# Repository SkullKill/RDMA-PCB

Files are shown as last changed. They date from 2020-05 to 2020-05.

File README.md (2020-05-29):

# RDMA-PCB
Rpi Dead Man Alarm - PCB and 3D case - Occupancy Monitoring - Raspberry Pi hat

24-RDMA-Case-04.jpg


23-RDMA-Case-03.jpg


07-RDMAweb-02.jpg


Video of it in action
Video of it in action (https://youtu.be/Ym4e5IUdtps)

## V 1.0 29/05/2020 - Initial Release

  ------------------------------------------------------------
## PCB Board Used

Ready to use PCB Board

https://www.skstore.com.au/electronics/pcb/RDMA

PCB Design Files / gerber files

[RDMA-PCB](https://github.com/SkullKill/RDMA-PCB)

3D Printed Case design files / STL

[RDMA-PCB](https://github.com/SkullKill/RDMA-PCB)

https://www.thingiverse.com/thing:4406335

https://www.myminifactory.com/object/3d-print-123446

FYI Gerber files are in the release section

https://github.com/SkullKill/RDMA-PCB/releases

more pictures in the wiki

https://github.com/SkullKill/RDMA-PCB/wiki

18-RDMA-Wiring-01.jpg


10-RDMA-FrontR-V1.0.jpg


15-RDMA-Back-BoardOnly-V1.0.jpg


  ------------------------------------------------------------
## Schematics

09-RDMA-schematics-v1.0.jpg


  ------------------------------------------------------------
## MecanicalDrawing

1 to 1 scale 

https://github.com/SkullKill/RDMA-PCB/blob/master/Case/RDMAcase-MecanicalDrawing-V1.0.pdf

please use PDF version, and print to scale


  ------------------------------------------------------------
## Code Used

[RDMA](https://github.com/SkullKill/RDMA)

  ------------------------------------------------------------

PCB features

* Step down DC DC regulator (12v will power both the pi and PIR sensor)
* Input has a self reset fuse, and reverse polarity protection.
* Physical on/off switch when powered via 12v
* Back power protection to allow pi to provide power.
* RTC clock
* Segment display (to display time left before alarm is triggered)
* Ability to trigger 3 X 5V object (e.g buzzer or lights) (will probably only populate one for the buzzer)
* The above trigger can be set to either 5V or 12V.
* Built in buzzer (to alert operator 1 min before alarm is triggered and SMS are sent out)
* 1-wire rail (possibility to add a number of DS18B20 temperature sensors)
* 2 physical button, one to manually reset the timer, or if hold for a few sec, will extend the timer once. Other button is to shutdown/unused.
* Ability to add external buttons.
* 1 configurable status light. (on when the service is running)
* All button, including PIR input has a physical denounce to eliminate noise/false alarm.
* EEPROM as per pi hat requirement (will probably not populate)
* Screw terminal for all connectors. No crimping required.

---------------------------

A 12V , 1A PSU should work, however, to be on the safe side, use a 12V, 2A PSU

Standard wall mount sensor DG65
https://www.paradox.com/Products/default.asp?CATID=8&SUBCATID=79&PRD=1389

swivel mount for DG65
https://www.paradox.com/Products/default.asp?CATID=8&SUBCATID=81&PRD=456

---------------------------

if the service is not running after restarting, GPIO 8 would be on, which would make the buzzer turn on. to turn it off, use the following.

    gpio readall
    gpio -g mode 8 output
    gpio -g write 8 0

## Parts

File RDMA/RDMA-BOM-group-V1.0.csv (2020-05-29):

Reference | Quantity | Value | Footprint | Datasheet | Alt | LCSC | LCSCweb | MPN | ALT | MPNweb | web
BT1 | 1 | Coin_1220 | RDMA:BatteryHolder_Keystone_1056_1x1220 | https://datasheet.lcsc.com/szlcsc/Q-J-CR1220-2_C70381.pdf |  | C70381 | https://lcsc.com/product-detail/Battery-Holders-Clips-Contacts_CR1220-2-Battery-horizontal-base_C70381.html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 | CR1220-2 | C238067
BZ1 | 1 | Buzzer_Active | RDMA:Buzzer_9x5.5RM5.0 | https://datasheet.lcsc.com/szlcsc/1811141138_Jiangsu-Huaneng-Elec-HNB09A05_C96493.pdf |  | C96493 | https://lcsc.com/product-detail/Buzzers_Jiangsu-Huaneng-Elec-HNB09A05_C96493.html | HNB09A05
C4 C1 C7 | 3 | 22UF-25V | Capacitor_SMD:C_0805_2012Metric | https://datasheet.lcsc.com/szlcsc/Samsung-Electro-Mechanics-CL21A226MAQNNNE_C45783.pdf |  | C45783 | https://lcsc.com/product-detail/Multilayer-Ceramic-Capacitors-MLCC-SMD-SMT_SAMSUNG_CL21A226MAQNNNE_22uF-226-20-25V_C45783.html | CL21A226MAQNNNE | C86816
C5 C3 C6 C9 C2 C12 C10 C11 C8 | (9-2)=7 | 100nF-50V | Capacitor_SMD:C_0603_1608Metric | https://datasheet.lcsc.com/szlcsc/YAGEO-AC0603KRX7R9BB104_C149620.pdf |  | C149620 | https://lcsc.com/product-detail/Multilayer-Ceramic-Capacitors-MLCC-SMD-SMT_YAGEO-AC0603KRX7R9BB104_C149620.html | AC0603KRX7R9BB104
D1 D5 D7 | (3-1)=2 | SOD1F7 | Diode_SMD:D_SOD-123 | https://datasheet.lcsc.com/szlcsc/1903041730_MDD-Jiangsu-Yutai-Elec-SOD1F7_C33221.pdf |  | C33221 | https://lcsc.com/product-detail/Diodes-Rectifiers-Fast-Recovery_Jiangsu-Yutai-Elec-SOD1F7_C33221.html | SOD1F7
D11 D3 D6 | (3-1)=2 | LED-Yellow | LED_SMD:LED_0603_1608Metric | https://datasheet.lcsc.com/szlcsc/Foshan-NationStar-Optoelectronics-FC-DA1608HYK-588J_C84268.pdf |  | C84268 | https://lcsc.com/product-detail/Light-Emitting-Diodes-LED_Yellow-light-SMDLED-70-150mcd_C84268.html | FC-DA1608HYK-588J
D4 D2 | 2 | LED-Green | LED_SMD:LED_0603_1608Metric | https://datasheet.lcsc.com/szlcsc/Orient-ORH-G36G_C205443.pdf |  | C205443 | https://lcsc.com/product-detail/Light-Emitting-Diodes-LED_0603-green_C205443.html | ORH-G36G
F1 | 1 | PTC-2A-16V | Fuse:Fuse_1812_4532Metric_Pad1.30x3.40mm_HandSolder | https://datasheet.lcsc.com/szlcsc/SOCAY-Elec-SCF200-16-1812R_C305617.pdf |  | C305617 | https://lcsc.com/product-detail/Others_SOCAY-Elec-SCF200-16-1812R_C305617.html | SCF200-16-1812R
J1 | 1 | Raspberry_Pi_2_3 | Connector_PinSocket_2.54mm:PinSocket_2x20_P2.54mm_Vertical | https://www.raspberrypi.org/documentation/hardware/raspberrypi/schematics/rpi_SCH_3bplus_1p0_reduced.pdf | C35165 | C50982 | https://lcsc.com/product-detail/Pin-Header-Female-Header_Boom-Precision-Elec-2-54mm-2-20PFemale-header_C50982.html
J16 | 1 | 12Vpsu | pi-template:TerminalBlock_bornier-2_P5.08mm | https://datasheet.lcsc.com/szlcsc/Ningbo-Kangnex-Elec-WJ126V-5-0-2P_C8404.pdf |  | C8404 | https://lcsc.com/product-detail/Pluggable-System-Terminal-Block_Ningbo-Kangnex-Elec-WJ126V-5-0-2P_C8404.html | WJ126V-5.0-2P
J2 | 1 | Screw_Terminal_01x04_Left_Top | pi-template:TerminalBlock_TE_282834-4_1x04_P2.54mm_Horizontal | ~ |  |  |  | KF128-2.54-4P |  | http://en.cnkefa.com/index.php?c=product&id=159 | https://www.aliexpress.com/store/group/Connection-terminal/4657016_515213135.html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
J22 | 1 | ProgrammingJumper | Connector_PinHeader_2.54mm:PinHeader_1x02_P2.54mm_Vertical | ~ |  | C124375 | https://lcsc.com/product-detail/Pin-Header-Female-Header_Shenzhen-Cankemeng-Headers-Pins-1-2P-2-54mm-Straight-line_C124375.html
J3 | 1 | Screw_Terminal_01x04_Left_Bottom | pi-template:TerminalBlock_TE_282834-4_1x04_P2.54mm_Horizontal | ~ |  |  |  | KF128-2.54-4P |  | http://en.cnkefa.com/index.php?c=product&id=159 | https://www.aliexpress.com/store/group/Connection-terminal/4657016_515213135.html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
J4 | 1 | Screw_Terminal_01x08_Bottom_Left | pi-template:TerminalBlock_TE_282834-8_1x08_P2.54mm_Horizontal | ~ |  |  |  | KF128-2.54-8P |  | http://en.cnkefa.com/index.php?c=product&id=159
J5 | 1 | Screw_Terminal_01x06_Top_Right | pi-template:TerminalBlock_TE_282834-6_1x06_P2.54mm_Horizontal | ~ |  |  |  | KF128-2.54-6P |  | http://en.cnkefa.com/index.php?c=product&id=159
JP2 JP1 | 2 | SolderJumper_2_Open | Resistor_SMD:R_0805_2012Metric | https://datasheet.lcsc.com/szlcsc/YAGEO-RC0805JR-070RL_C96345.pdf |  | C96345 | https://lcsc.com/product-detail/Chip-Resistor-Surface-Mount_0R-0R-5_C96345.html | RC0805JR-070RL
JP3 JP7 | 2 | Jumper_3_Bridged12 | Connector_PinHeader_2.54mm:PinHeader_1x03_P2.54mm_Vertical | https://datasheet.lcsc.com/szlcsc/Boom-Precision-Elec-Header-2-54mm-1-3P_C49257.pdf |  | C49257 | https://lcsc.com/product-detail/Pin-Header-Female-Header_Boom-Precision-Elec-Header-2-54mm-1-3P_C49257.html
L1 | 1 | 3.3UH-8.5A | pi-template:L_6.3x6.3_H3_HandSolder | https://datasheet.lcsc.com/szlcsc/1812181433_MAZO-MPCA-0630-3R3-M_C268402.pdf |  | C268402 | https://lcsc.com/product-detail/Others_MAZO-MPCA-0630-3R3-M_C268402.html | MPCA-0630-3R3-M | C207839
Q11 | 1 | DMMT5401 | Package_TO_SOT_SMD:SOT-23-6 | https://datasheet.lcsc.com/szlcsc/Diodes-Incorporated-DMMT5401-7-F_C154733.pdf |  | C154733 | https://lcsc.com/product-detail/Transistors-NPN-PNP_DIODES_DMMT5401-7-F_DMMT5401-7-F_C154733.html | DMMT5401-7-F
Q12 Q1 | 2 | DMG2305UX | Package_TO_SOT_SMD:SOT-23 | https://datasheet.lcsc.com/szlcsc/Diodes-Incorporated-DMG2305UX-13_C144153.pdf |  | C144153 | https://lcsc.com/product-detail/MOSFET_Diodes-Incorporated_DMG2305UX-13_Diodes-Incorporated-DMG2305UX-13_C144153.html | DMG2305UX-13
Q2 Q6 Q7 | 3 | BSS138 | Package_TO_SOT_SMD:SOT-23 | https://datasheet.lcsc.com/szlcsc/Diodes-Incorporated-BSS138-7-F_C40912.pdf |  | C40912 | https://lcsc.com/product-detail/MOSFET_Diodes-Incorporated_BSS138-7-F_Diodes-Incorporated-BSS138-7-F_C40912.html | BSS138-7-F
Q3 Q4 Q5 | 3 | DMN2056U | Package_TO_SOT_SMD:SOT-23 | http://www.diodes.com/assets/Datasheets/DMN2056U.pdf |  | C332302 | https://lcsc.com/product-detail/MOSFET_Diodes-Incorporated_DMN2056U-7_Diodes-Incorporated-DMN2056U-7_C332302.html | DMN2056U-7
R1 R13 R17 | (3-1)=2 | 2.2KΩ | Resistor_SMD:R_0603_1608Metric | https://datasheet.lcsc.com/szlcsc/YAGEO-RC0603FR-072K2L_C114662.pdf |  | C114662 | https://lcsc.com/product-detail/Chip-Resistor-Surface-Mount_2-2KR-2201-1_C114662.html | RC0603FR-072K2L
R15 | 1 | 47KΩ | Resistor_SMD:R_0603_1608Metric | https://datasheet.lcsc.com/szlcsc/YAGEO-AC0603FR-0747KL_C111134.pdf |  | C111134 | https://lcsc.com/product-detail/Chip-Resistor-Surface-Mount_47KR-4702-1_C111134.html | AC0603FR-0747KL | RC0603FR-0747KL
R19 | (1-1)=0 | 1KΩ | Resistor_SMD:R_0603_1608Metric | https://datasheet.lcsc.com/szlcsc/YAGEO-RC0603FR-071KL_C22548.pdf |  | C22548 | https://lcsc.com/product-detail/Chip-Resistor-Surface-Mount_1KR-1001-1_C22548.html | RC0603FR-071KL
R21 R23 R24 | 3 | 4.7KΩ | Resistor_SMD:R_0603_1608Metric | https://datasheet.lcsc.com/szlcsc/YAGEO-RC0603FR-074K7L_C99782.pdf |  | C99782 | https://lcsc.com/product-detail/Chip-Resistor-Surface-Mount_4-7KR-472-1_C99782.html | RC0603FR-074K7L
R22 R28 | (2-2)=0 | 3.9KΩ | Resistor_SMD:R_0603_1608Metric | https://datasheet.lcsc.com/szlcsc/YAGEO-RC0603FR-073K9L_C114616.pdf |  | C114616 | https://lcsc.com/product-detail/Chip-Resistor-Surface-Mount_3-9KR-3901-1_C114616.html | RC0603FR-073K9L
R26 | 1 | 57.6KΩ | Resistor_SMD:R_0603_1608Metric | https://datasheet.lcsc.com/szlcsc/YAGEO-RC0603FR-0757K6L_C245983.pdf |  | C245983 | https://lcsc.com/product-detail/Others_YAGEO-RC0603FR-0757K6L_C245983.html | RC0603FR-0757K6L
R27 R6 R35 | (3-1)=2 | 330Ω | Resistor_SMD:R_0603_1608Metric | https://datasheet.lcsc.com/szlcsc/YAGEO-RC0603FR-07330RL_C105881.pdf |  | C105881 | https://lcsc.com/product-detail/Chip-Resistor-Surface-Mount_330R-330R-1_C105881.html | RC0603FR-07330RL
R34 R32 R7 | 3 | 1.2KΩ | Resistor_SMD:R_0603_1608Metric | https://datasheet.lcsc.com/szlcsc/YAGEO-RC0603FR-071K2L_C114605.pdf |  | C114605 | https://lcsc.com/product-detail/Chip-Resistor-Surface-Mount_1-2KR-1201-1_C114605.html | RC0603FR-071K2L
R4 R25 R11 R2 R8 R12 R16 R33 R31 R18 R29 R20 R30 | (13-2)=11 | 10KΩ | Resistor_SMD:R_0603_1608Metric | https://datasheet.lcsc.com/szlcsc/YAGEO-RC0603FR-0710KL_C98220.pdf |  | C98220 | https://lcsc.com/product-detail/Chip-Resistor-Surface-Mount_10KR-1002-1_C98220.html | RC0603FR-0710KL
R5 R3 R10 R14 | (4-1)=3 | 100Ω | Resistor_SMD:R_0603_1608Metric | https://datasheet.lcsc.com/szlcsc/YAGEO-RC0603FR-07100RL_C105588.pdf |  | C105588 | https://lcsc.com/product-detail/Chip-Resistor-Surface-Mount_100R-1000-1_C105588.html | RC0603FR-07100RL
SW1 | 1 | 5V Reg Sw on-off | Button_Switch_SMD:SW_SPDT_PCM12 | https://datasheet.lcsc.com/szlcsc/Korean-Hroparts-Elec-K3-1292S-P2_C145853.pdf |  | C145853 | https://lcsc.com/product-detail/Toggle-Switches_Korean-Hroparts-Elec-K3-1292S-P2_C145853.html | K3-1292S-P2
SW3 SW2 | 2 | SW_Push | RDMA:SW_SPST_TL3305A | ~ |  | C174049 | https://lcsc.com/product-detail/Tactile-Switches_Switch-4-5-4-5-3-8mm_C174049.html
U1 | 1 | TPS563200 | Package_TO_SOT_SMD:SOT-23-6_Handsoldering | http://www.ti.com/lit/ds/symlink/tps563200.pdf |  | C97253 | https://lcsc.com/product-detail/DC-DC-Converters_TI_TPS563200DDCR_TPS563200DDCR_C97253.html | TPS563200DDCR
U2 | (1-1)=0 | CAT24C32 | Package_SO:SOIC-8_3.9x4.9mm_P1.27mm | https://datasheet.lcsc.com/szlcsc/ON-Semicon-ON-CAT24C32WI-GT3_C81193.pdf |  | C81193 | https://lcsc.com/product-detail/EEPROM_ON-Semicon_CAT24C32WI-GT3_ON-Semicon-ON-CAT24C32WI-GT3_C81193.html | CAT24C32WI-GT3
U3 | 1 | HT16K33-28 | Package_SO:SOIC-28W_7.5x17.9mm_P1.27mm | https://datasheet.lcsc.com/szlcsc/1811091023_Holtek-Semicon-HT16K33_C87502.pdf |  | C87502 | https://lcsc.com/product-detail/LED-Drivers_HT16K33_C87502.html
U4 | 1 | CC56-12EWA | Display_7Segment:CA56-12EWA | http://www.kingbrightusa.com/images/catalog/SPEC/CA56-12EWA.pdf |  | C10709 | https://lcsc.com/product-detail/Led-Segment-Display_Made-in-China-4Bit0-56Inch-red-digital-LED_C10709.html
U5 | 1 | DS3231MZ | Package_SO:SOIC-8_3.9x4.9mm_P1.27mm | https://datasheet.lcsc.com/szlcsc/Maxim-Integrated-DS3231MZ_C107410.pdf |  | C107410 | https://lcsc.com/product-detail/Real-time-Clocks_MAXIM_DS3231MZ_DS3231MZ_C107410.html | DS3231MZ+TRL

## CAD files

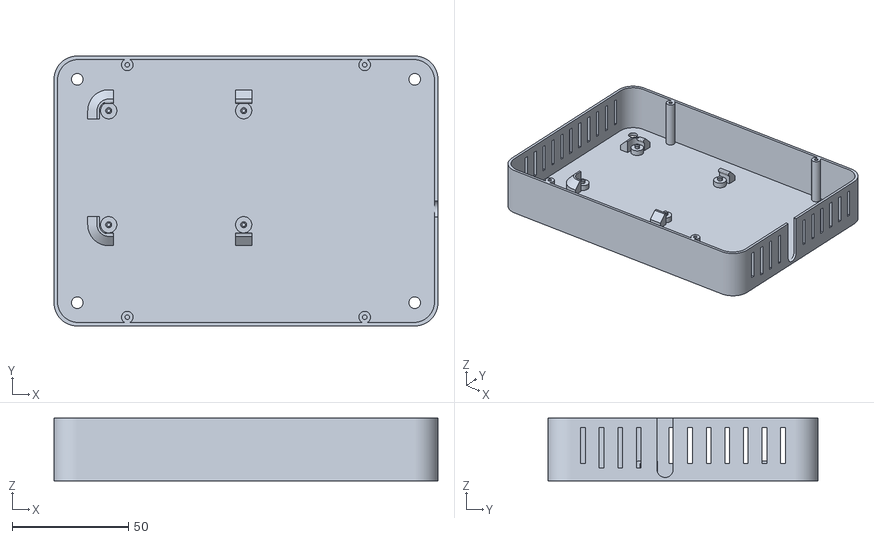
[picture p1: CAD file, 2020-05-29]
Case/RDMAcase-Base.stl
165.0 x 116.0 x 27.0

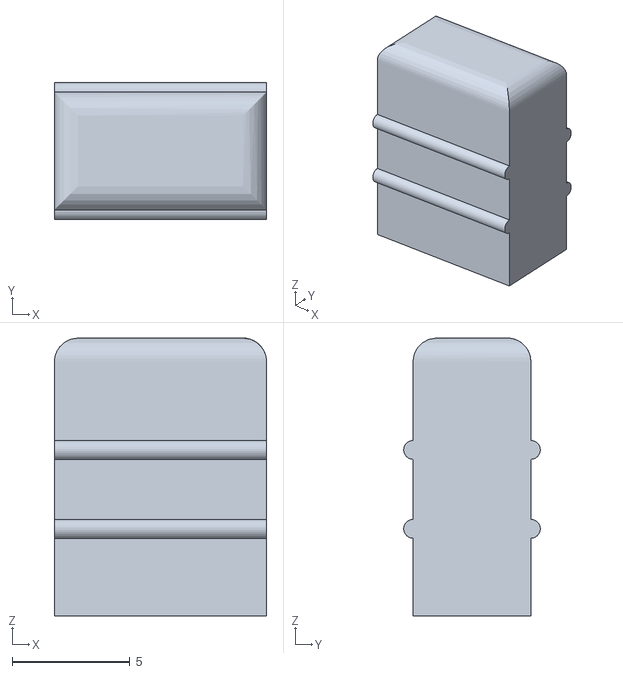
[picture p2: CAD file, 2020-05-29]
Case/RDMAcase-ResetButton-0.40.stl
9.00 x 5.79 x 11.8

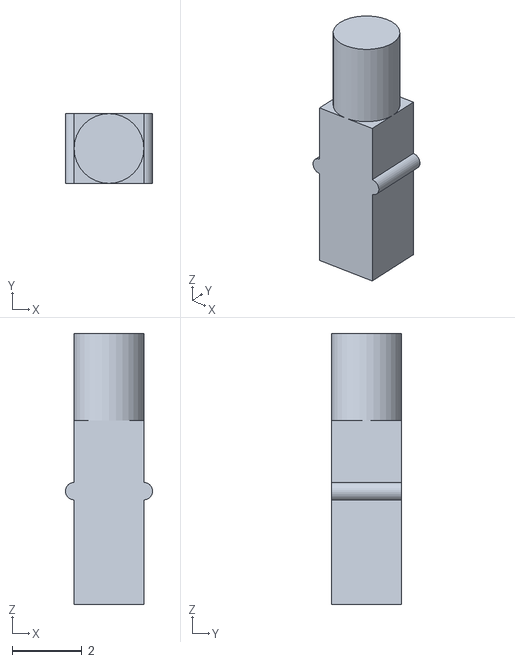
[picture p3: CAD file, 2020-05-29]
Case/RDMAcase-ShutdownButton-0.25-1L.stl
2.50 x 2.00 x 7.77

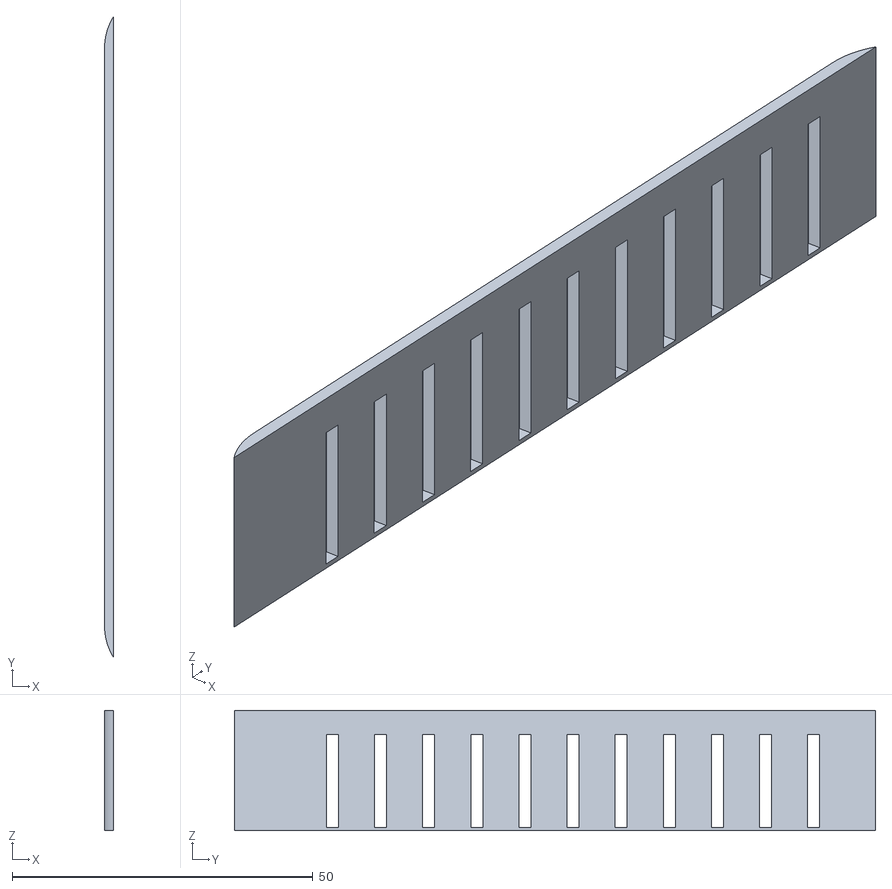
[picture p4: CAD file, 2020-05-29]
Case/retraction_test_skip.stl
1.50 x 106.5 x 20.0

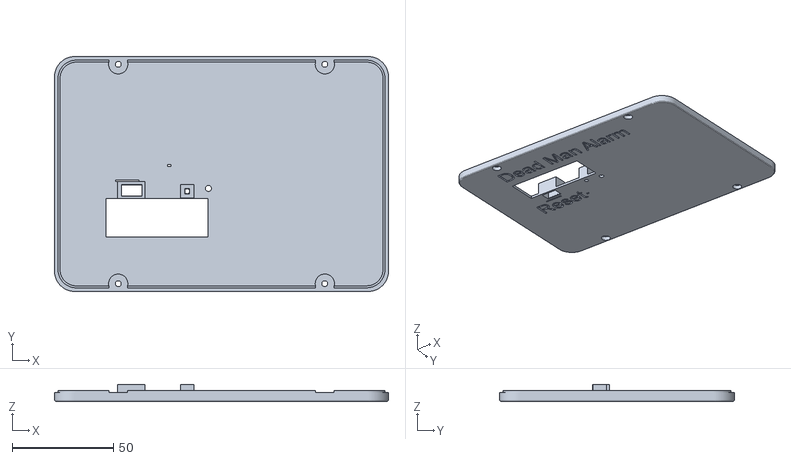
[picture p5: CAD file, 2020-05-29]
Case/RDMAcase-Cover.stl
165.0 x 116.0 x 8.50

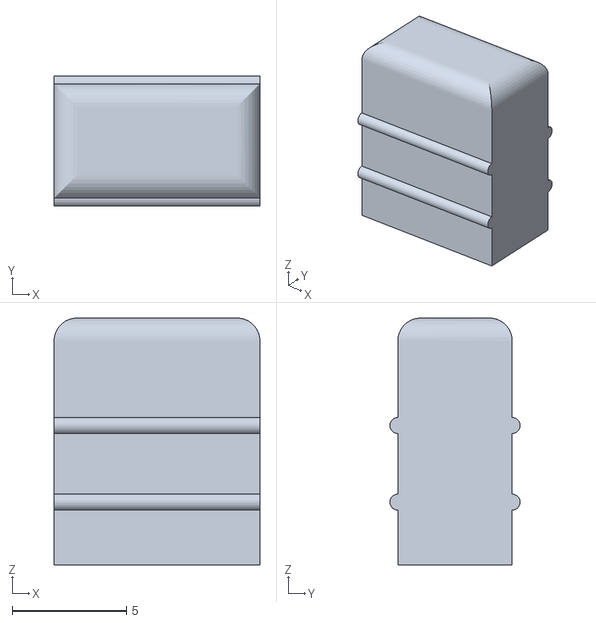
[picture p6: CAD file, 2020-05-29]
Case/RDMAcase-ResetButton-0.35-1L.stl
9.00 x 5.69 x 10.8

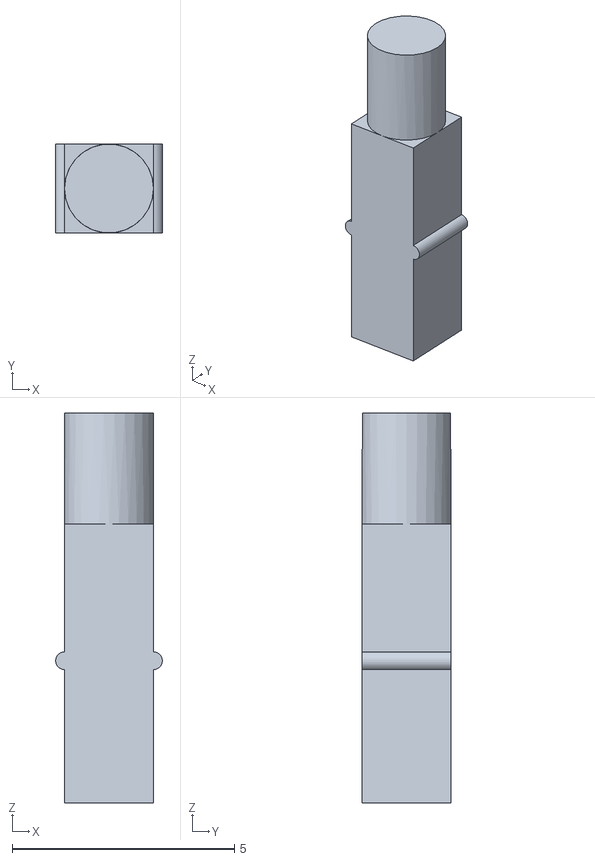
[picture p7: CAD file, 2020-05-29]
Case/RDMAcase-ShutdownButton-0.20.stl
2.40 x 2.00 x 8.77

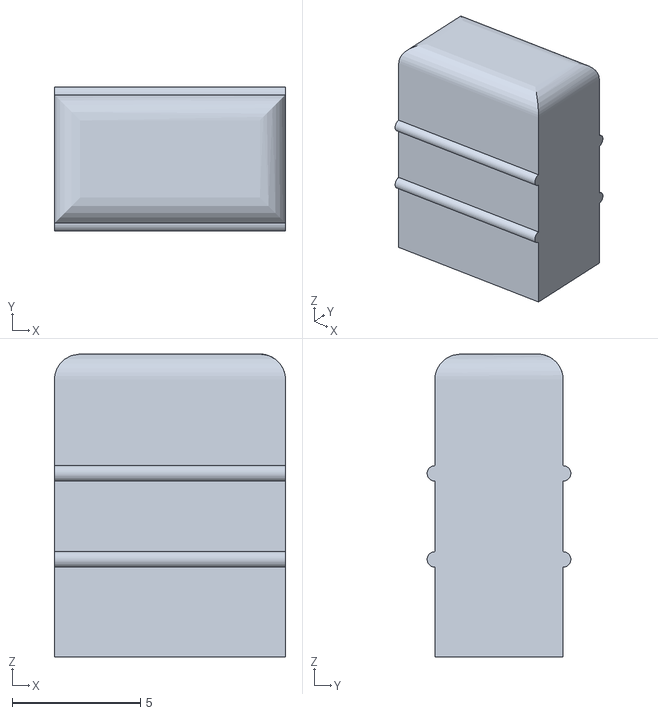
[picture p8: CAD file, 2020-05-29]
Case/RDMAcase-ResetButton-0.30.stl
9.00 x 5.60 x 11.8

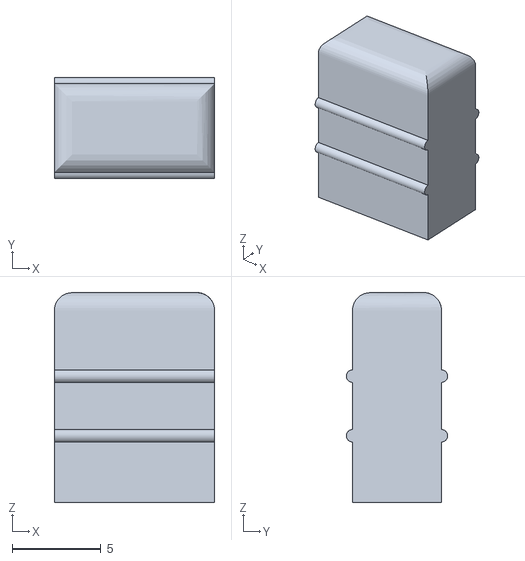
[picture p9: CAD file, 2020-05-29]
Case/RDMAcase-ResetButton-0.35.stl
9.00 x 5.69 x 11.8

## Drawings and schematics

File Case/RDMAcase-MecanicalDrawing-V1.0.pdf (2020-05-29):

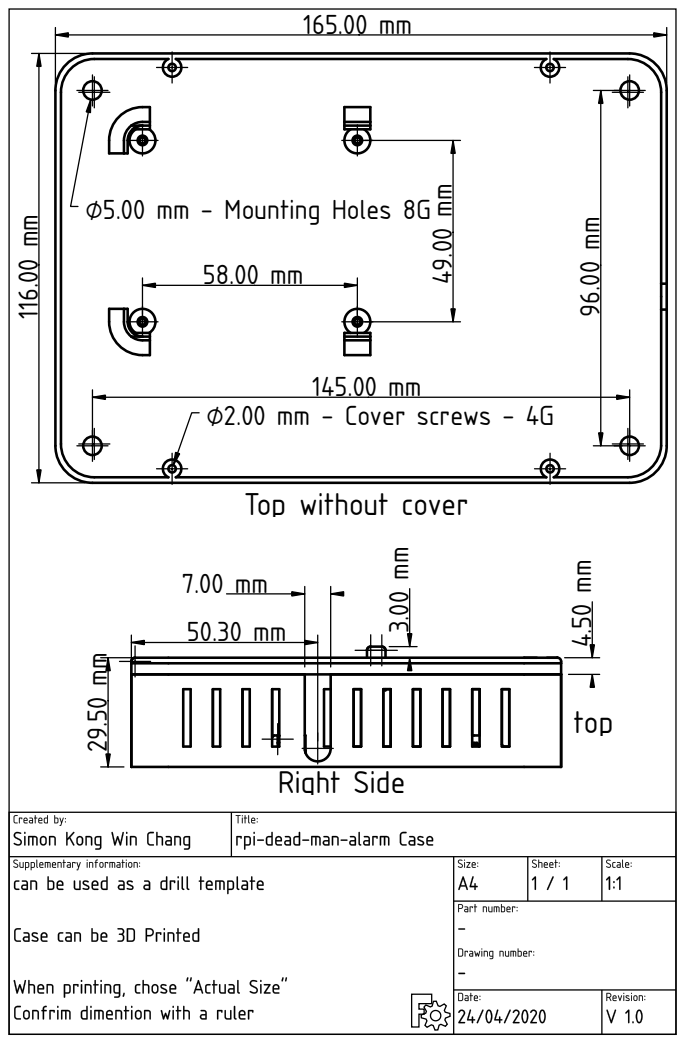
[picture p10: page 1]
Right Side; top

⌀5.00 mm - Mounting Holes 8G

⌀2.00 mm - Cover screws - 4G

Top without cover

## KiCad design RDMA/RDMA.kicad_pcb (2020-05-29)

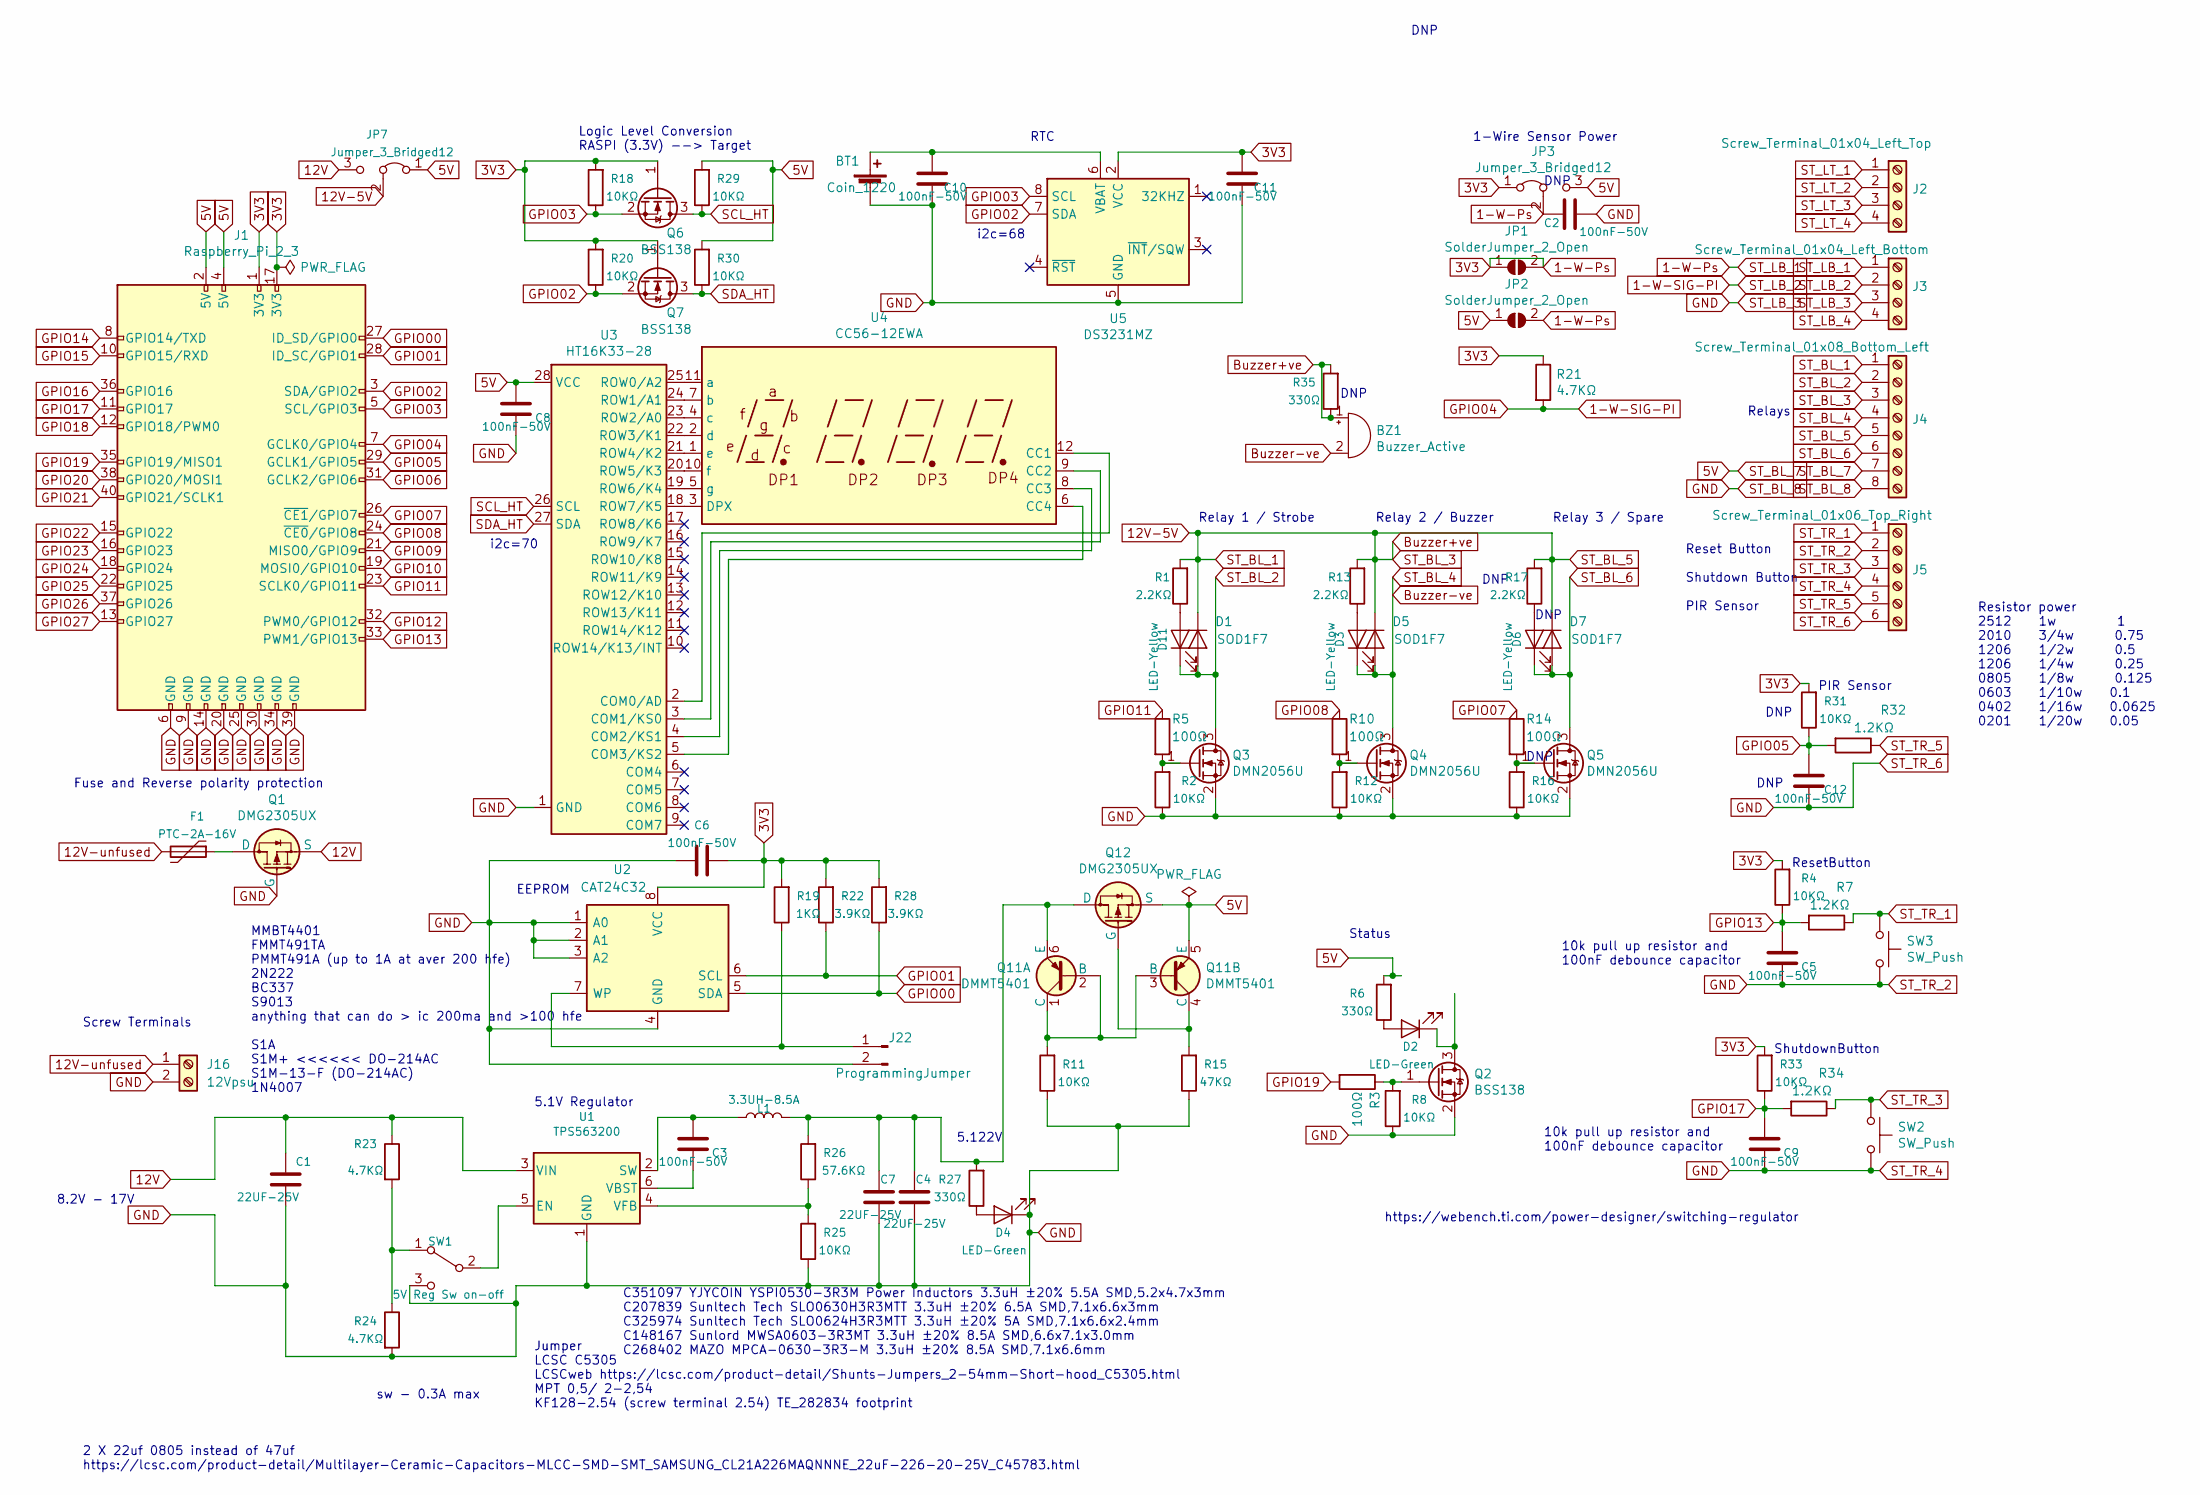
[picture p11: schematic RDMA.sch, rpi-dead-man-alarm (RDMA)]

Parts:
BT1: Coin_1220; BatteryHolder_Keystone_1056_1x1220; MPN CR1220-2; LCSC C70381
BZ1: Buzzer_Active; Buzzer_9x5.5RM5.0; MPN HNB09A05; LCSC C96493
C1, C4, C7: 22UF-25V; C_0805_2012Metric; MPN CL21A226MAQNNNE; LCSC C45783
C2, C3, C5, C6, C8, C9, C10, C11, C12: 100nF-50V; C_0603_1608Metric; MPN AC0603KRX7R9BB104; LCSC C149620
D1, D5, D7: SOD1F7; D_SOD-123; MPN SOD1F7; LCSC C33221
D2, D4: LED-Green; LED_0603_1608Metric; MPN ORH-G36G; LCSC C205443
D3, D6, D11: LED-Yellow; LED_0603_1608Metric; MPN FC-DA1608HYK-588J; LCSC C84268
F1: PTC-2A-16V; Fuse_1812_4532Metric_Pad1.30x3.40mm_HandSolder; MPN SCF200-16-1812R; LCSC C305617
J1: Raspberry_Pi_2_3; PinSocket_2x20_P2.54mm_Vertical; LCSC C50982
J2: Screw_Terminal_01x04_Left_Top; TerminalBlock_TE_282834-4_1x04_P2.54mm_Horizontal; MPN KF128-2.54-4P
J3: Screw_Terminal_01x04_Left_Bottom; TerminalBlock_TE_282834-4_1x04_P2.54mm_Horizontal; MPN KF128-2.54-4P
J4: Screw_Terminal_01x08_Bottom_Left; TerminalBlock_TE_282834-8_1x08_P2.54mm_Horizontal; MPN KF128-2.54-8P
J5: Screw_Terminal_01x06_Top_Right; TerminalBlock_TE_282834-6_1x06_P2.54mm_Horizontal; MPN KF128-2.54-6P
J16: 12Vpsu; TerminalBlock_bornier-2_P5.08mm; MPN WJ126V-5.0-2P; LCSC C8404
J22: ProgrammingJumper; PinHeader_1x02_P2.54mm_Vertical; LCSC C124375
JP1, JP2: SolderJumper_2_Open; R_0805_2012Metric; MPN RC0805JR-070RL; LCSC C96345
JP3, JP7: Jumper_3_Bridged12; PinHeader_1x03_P2.54mm_Vertical; LCSC C49257
L1: 3.3UH-8.5A; L_6.3x6.3_H3_HandSolder; MPN MPCA-0630-3R3-M; LCSC C268402
Q1, Q12: DMG2305UX; SOT-23; MPN DMG2305UX-13; LCSC C144153
Q2, Q6, Q7: BSS138; SOT-23; MPN BSS138-7-F; LCSC C40912
Q3, Q4, Q5: DMN2056U; SOT-23; MPN DMN2056U-7; LCSC C332302
Q11: DMMT5401; SOT-23-6; MPN DMMT5401-7-F; LCSC C154733
R1, R13, R17: 2.2KΩ; R_0603_1608Metric; MPN RC0603FR-072K2L; LCSC C114662
R2, R4, R8, R11, R12, R16, R18, R20, R25, R29, R30, R31, R33: 10KΩ; R_0603_1608Metric; MPN RC0603FR-0710KL; LCSC C98220
R3, R5, R10, R14: 100Ω; R_0603_1608Metric; MPN RC0603FR-07100RL; LCSC C105588
R6, R27, R35: 330Ω; R_0603_1608Metric; MPN RC0603FR-07330RL; LCSC C105881
R7, R32, R34: 1.2KΩ; R_0603_1608Metric; MPN RC0603FR-071K2L; LCSC C114605
R15: 47KΩ; R_0603_1608Metric; MPN AC0603FR-0747KL; LCSC C111134
R19: 1KΩ; R_0603_1608Metric; MPN RC0603FR-071KL; LCSC C22548
R21, R23, R24: 4.7KΩ; R_0603_1608Metric; MPN RC0603FR-074K7L; LCSC C99782
R22, R28: 3.9KΩ; R_0603_1608Metric; MPN RC0603FR-073K9L; LCSC C114616
R26: 57.6KΩ; R_0603_1608Metric; MPN RC0603FR-0757K6L; LCSC C245983
SW1: 5V Reg Sw on-off; SW_SPDT_PCM12; MPN K3-1292S-P2; LCSC C145853
SW2, SW3: SW_Push; SW_SPST_TL3305A; LCSC C174049
U1: TPS563200; SOT-23-6_Handsoldering; MPN TPS563200DDCR; LCSC C97253
U2: CAT24C32; SOIC-8_3.9x4.9mm_P1.27mm; MPN CAT24C32WI-GT3; LCSC C81193
U3: HT16K33-28; SOIC-28W_7.5x17.9mm_P1.27mm; LCSC C87502
U4: CC56-12EWA; CA56-12EWA; LCSC C10709
U5: DS3231MZ; SOIC-8_3.9x4.9mm_P1.27mm; MPN DS3231MZ+TRL; LCSC C107410

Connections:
1-W-Ps: C2.2, C6.2, C11.2, J1.1 (3V3), J1.17 (3V3), J3.1, JP1.1 (A), JP1.2 (B), JP2.2 (B), JP3.1 (A), JP3.2 (C), Q6.1 (G), Q7.1 (G), R4.2, R18.2, R19.2, R20.2, R21.1, R22.2, R28.2, R31.2, R33.2, U2.8 (VCC), U5.2 (VCC)
1-W-SIG-PI: J1.7 (GCLK0/GPIO4), J3.2, R21.2
5V: C8.2, J1.2 (5V), J1.4 (5V), J4.7, JP2.1 (A), JP3.3 (B), JP7.1 (A), Q11.5 (E), Q12.2 (S), R6.2, R29.2, R30.2, U3.28 (VCC)
12V: C1.2, JP7.3 (B), Q1.2 (S), R23.1, U1.3 (VIN)
12V-5V: BZ1.1 (-), D1.1 (K), D5.1 (K), D7.1 (K), J4.1, J4.3, J4.5, JP7.2 (C), R1.2, R13.2, R17.2, R35.1, R35.2
12V-unfused: F1.2, J16.1
Buzzer-ve: BZ1.2 (+), D3.1 (K), D5.2 (A), J4.4, Q4.3 (D)
GND: BT1.2 (-), C1.1, C2.1, C4.2, C5.2, C6.1, C7.1, C8.1, C9.2, C10.1, C11.1, C12.2, D4.1 (K), J1.6 (GND), J1.9 (GND), J1.14 (GND), J1.20 (GND), J1.25 (GND), J1.30 (GND), J1.34 (GND), J1.39 (GND), J3.3, J4.8, J5.2, J5.4, J5.6, J16.2, J22.2, Q1.1 (G), Q2.2 (S), Q3.2 (S), Q4.2 (S), Q5.2 (S), R2.1, R8.1, R11.1, R12.1, R15.1, R16.1, R24.2, R25.1, SW1.3 (C), SW2.2, SW3.2, U1.1 (GND), U2.1 (A0), U2.2 (A1), U2.3 (A2), U2.4 (GND), U3.1 (GND), U5.5 (GND)
GPIO00: J1.27 (ID_SD/GPIO0), R28.1, U2.5 (SDA)
GPIO01: J1.28 (ID_SC/GPIO1), R22.1, U2.6 (SCL)
GPIO02: J1.3 (SDA/GPIO2), Q7.2 (S), R20.1, U5.7 (SDA)
GPIO03: J1.5 (SCL/GPIO3), Q6.2 (S), R18.1, U5.8 (SCL)
GPIO05: C12.1, J1.29 (GCLK1/GPIO5), R31.1, R32.2
GPIO06: J1.31 (GCLK2/GPIO6)
GPIO07: J1.26 (~CE1~/GPIO7), R14.1
GPIO08: J1.24 (~CE0~/GPIO8), R10.1
GPIO09: J1.21 (MISO0/GPIO9)
GPIO10: J1.19 (MOSI0/GPIO10)
GPIO11: J1.23 (SCLK0/GPIO11), R5.1
GPIO12: J1.32 (PWM0/GPIO12)
GPIO13: C5.1, J1.33 (PWM1/GPIO13), R4.1, R7.2
GPIO14: J1.8 (GPIO14/TXD)
GPIO15: J1.10 (GPIO15/RXD)
GPIO16: J1.36 (GPIO16)
GPIO17: C9.1, J1.11 (GPIO17), R33.1, R34.2
GPIO18: J1.12 (GPIO18/PWM0)
GPIO19: J1.35 (GPIO19/MISO1), R3.2
GPIO20: J1.38 (GPIO20/MOSI1)
GPIO21: J1.40 (GPIO21/SCLK1)
GPIO22: J1.15 (GPIO22)
GPIO23: J1.16 (GPIO23)
GPIO24: J1.18 (GPIO24)
GPIO25: J1.22 (GPIO25)
GPIO26: J1.37 (GPIO26)
GPIO27: J1.13 (GPIO27)
unnamed: BT1.1 (+), C10.2, U5.6 (VBAT)
unnamed: C3.1, L1.1, U1.2 (SW)
unnamed: C3.2, U1.6 (VBST)
unnamed: C4.1, C7.2, L1.2, Q11.6 (E), Q12.3 (D), R26.2, R27.2
unnamed: D2.1 (K), Q2.3 (D)
unnamed: D2.2 (A), R6.1
unnamed: D3.2 (A), R13.1
unnamed: D4.2 (A), R27.1
unnamed: D6.2 (A), R17.1
unnamed: D11.2 (A), R1.1
unnamed: F1.1, Q1.3 (D)
unnamed: J22.1, R19.1, U2.7 (WP)
unnamed: Q2.1 (G), R3.1, R8.2
unnamed: Q3.1 (G), R2.2, R5.2
unnamed: Q4.1 (G), R10.2, R12.2
unnamed: Q5.1 (G), R14.2, R16.2
unnamed: Q11.1 (C), Q11.2 (B), Q11.3 (B), R11.2
unnamed: Q11.4 (C), Q12.1 (G), R15.2
unnamed: R23.2, R24.1, SW1.1 (A)
unnamed: R25.2, R26.1, U1.4 (VFB)
unnamed: SW1.2 (B), U1.5 (EN)
unnamed: U3.2 (COM0/AD), U4.12 (CC1)
unnamed: U3.3 (COM1/KS0), U4.9 (CC2)
unnamed: U3.4 (COM2/KS1), U4.8 (CC3)
unnamed: U3.5 (COM3/KS2), U4.6 (CC4)
unnamed: U3.18 (ROW7/K5), U4.3 (DPX)
unnamed: U3.19 (ROW6/K4), U4.5 (g)
unnamed: U3.20 (ROW5/K3), U4.10 (f)
unnamed: U3.21 (ROW4/K2), U4.1 (e)
unnamed: U3.22 (ROW3/K1), U4.2 (d)
unnamed: U3.23 (ROW2/A0), U4.4 (c)
unnamed: U3.24 (ROW1/A1), U4.7 (b)
unnamed: U3.25 (ROW0/A2), U4.11 (a)
SCL_HT: Q6.3 (D), R29.1, U3.26 (SCL)
SDA_HT: Q7.3 (D), R30.1, U3.27 (SDA)
ST_BL_2: D1.2 (A), D11.1 (K), J4.2, Q3.3 (D)
ST_BL_6: D6.1 (K), D7.2 (A), J4.6, Q5.3 (D)
ST_LB_4: J3.4
ST_TR_1: J5.1, R7.1, SW3.1
ST_TR_3: J5.3, R34.1, SW2.1
ST_TR_5: J5.5, R32.1

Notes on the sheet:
Screw Terminals
https://webench.ti.com/power-designer/switching-regulator
10k pull up resistor and 100nF debounce capacitor
5.122V
5.1V Regulator
8.2V - 17V
sw - 0.3A max
Fuse and Reverse polarity protection
Status
Relay 1 / Strobe
Relay 2 / Buzzer
Relay 3 / Spare
ResetButton
Relays
Reset Button Shutdown Button PIR Sensor
1-Wire Sensor Power
ShutdownButton
DNP
PIR Sensor
RTC
Logic Level Conversion RASPI (3.3V) --> Target
i2c=68
i2c=70
Resistor power 2512 1w 1 2010 3/4w 0.75 1206 1/2w 0.5 1206 1/4w 0.25 0805 1/8w 0.125 0603 1/10w 0.1 0402 1/16w 0.0625 0201 1/20w 0.05
MMBT4401 FMMT491TA PMMT491A (up to 1A at aver 200 hfe) 2N222 BC337 S9013 anything that can do > ic 200ma and >100 hfe S1A S1M+ <<<<<< DO-214AC S1M-13-F (DO-214AC) 1N4007
C351097 YJYCOIN YSPI0530-3R3M Power Inductors 3.3uH ±20% 5.5A SMD,5.2x4.7x3mm C207839 Sunltech Tech SLO0630H3R3MTT 3.3uH ±20% 6.5A SMD,7.1x6.6x3mm C325974 Sunltech Tech SLO0624H3R3MTT 3.3uH ±20% 5A SMD,7.1x6.6x2.4mm C148167 Sunlord MWSA0603-3R3MT 3.3uH ±20% 8.5A SMD,6.6x7.1x3.0mm C268402 MAZO MPCA-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
2 X 22uf 0805 instead of 47uf https://lcsc.com/product-detail/Multilayer-Ceramic-Capacitors-MLCC-SMD-SMT_SAMSUNG_CL21A226MAQNNNE_22uF-226-20-25V_C45783.html
Jumper LCSC C5305 LCSCweb https://lcsc.com/product-detail/Shunts-Jumpers_2-54mm-Short-hood_C5305.html MPT 0,5/ 2-2,54 KF128-2.54 (screw terminal 2.54) TE_282834 footprint
EEPROM

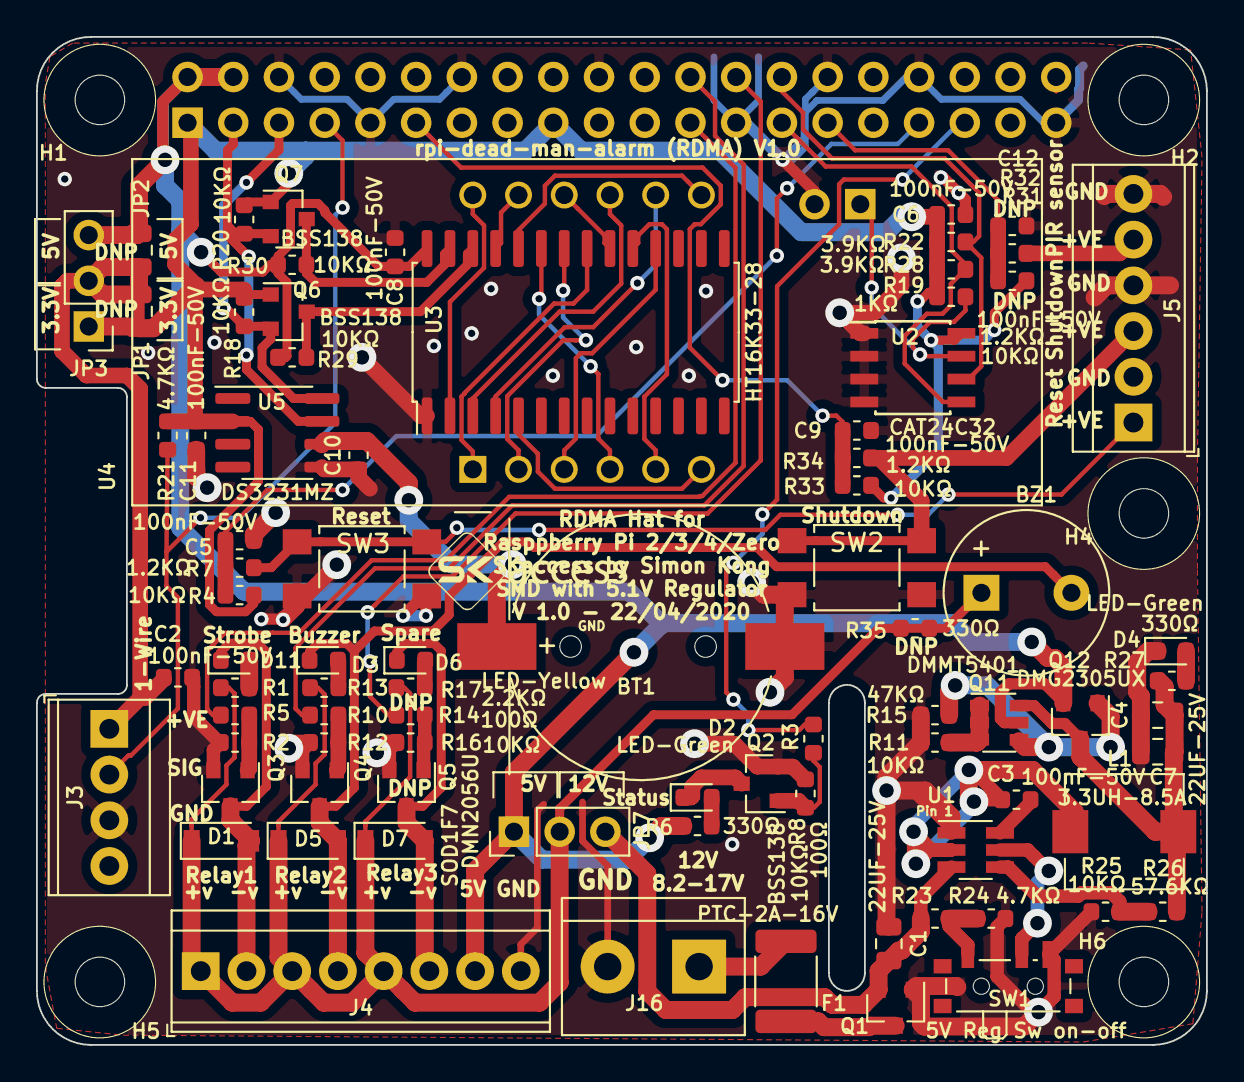
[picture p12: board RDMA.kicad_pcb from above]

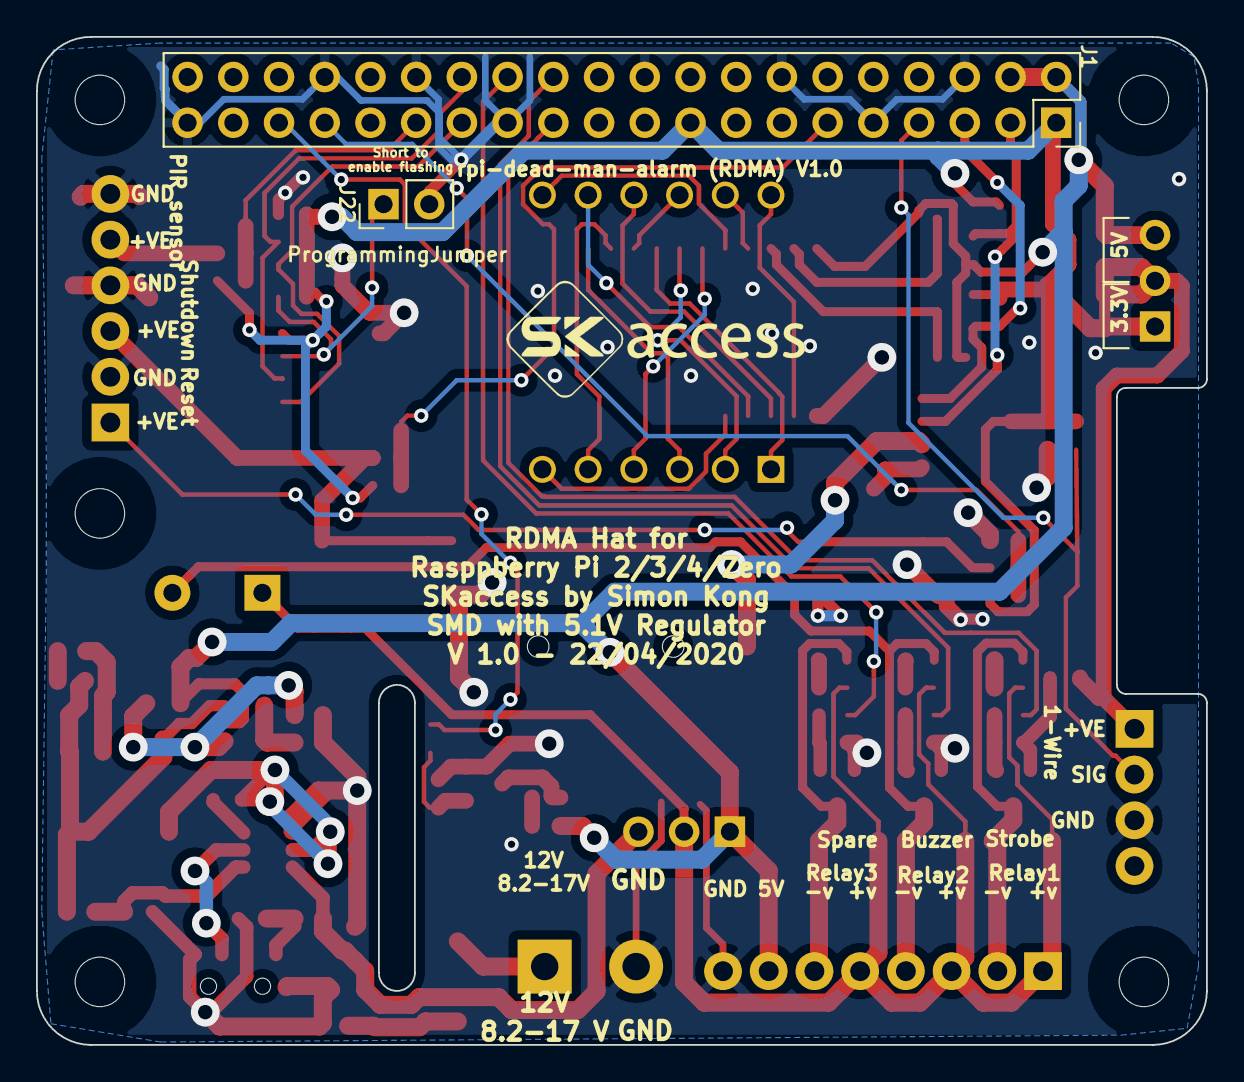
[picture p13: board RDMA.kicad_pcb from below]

Board: 2 copper layers, 65.0 x 56.0 mm, 90 parts (2 on the bottom side), 59 nets.

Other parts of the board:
H1, H2, H4, H5, H6: MountingHole; MountingHole_2.75mm_M2.5_NoPad
